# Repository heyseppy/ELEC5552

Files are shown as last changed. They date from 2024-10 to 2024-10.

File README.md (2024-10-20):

<p align="center">
  ELEC5552 Drone Image
  <h1>ELEC5552 Electrical Design Project</h1>
</p>

---

## Overview

This project encompasses hardware designs, build guides, and software implementations for developing a fully autonomous drone. The goal is to design and build a robust drone capable of autonomous line following, obstacle detection, and smooth transitions between manual and autonomous control modes.

### Key Features

- **Autonomous Line Following**  
  The drone adjusts its pitch and yaw to maintain alignment with a predefined path using a bottom-facing camera.

- **Obstacle Detection**  
  An ultrasonic sensor detects obstacles, allowing the drone to either stop or adjust its throttle to avoid collisions.

- **Safe Operation**  
  In the event of communication loss, the drone follows safety protocols to ensure secure operation.

- **Manual Mode**  
  The system enables manual control for the operator, with seamless switching between manual and autonomous modes.

---

## Hardware Requirements

- **Flight Controller**  
  Central unit that stabilizes and manages the drone’s flight based on input from sensors.

- **Bottom-facing Camera**  
  Provides vision for line/path detection to guide the drone during autonomous mode.

- **Ultrasonic Sensor**  
  Facilitates obstacle detection and altitude management to prevent collisions.

- **Motors and ESCs (Electronic Speed Controllers)**  
  Essential for precise control over throttle, pitch, and yaw during flight.

- **Radio or Wi-Fi Module**  
  Ensures wireless communication between the drone and the base station for real-time command transmission.

- **Battery (800mAh - 1S/2S)**  
  Powers the drone and onboard electronics.

---

## Software Requirements

- **Arduino IDE**  
  Development environment used to program the flight controller and integrate sensor inputs.

- **Communication Protocol**  
  Implements wireless communication between the drone and controller using protocols like LoRa, Wi-Fi, or proprietary radio systems.

- **Sensor Drivers**  
  Drivers or libraries are used for managing data from the ultrasonic sensor and camera.

---

## Contributors

- Jonathon Sader  
- William Hor  
- Sep Kimiaei  
- Carl Alvares  
- Liam Kubach  
- Aidan Crummey

---

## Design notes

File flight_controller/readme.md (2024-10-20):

## Understanding the CRSF Protocol

### What is CRSF?

**CRSF (Crossfire)** is a proprietary communication protocol developed by Team BlackSheep for long-range, low-latency communication between a transmitter and a receiver, typically used in RC (Radio Control) applications such as drones and other remote-controlled vehicles. CRSF is renowned for its high reliability, low latency, and efficient bandwidth utilization.

### Why CRSF?

- **Low Latency**: Ensures rapid response times, crucial for real-time control in dynamic environments.
- **High Reliability**: Maintains stable connections even in challenging conditions, minimizing packet loss.
- **Efficient Bandwidth**: Optimizes data transmission, allowing for more telemetry data without overloading the communication channel.
- **Extended Range**: Provides robust communication over longer distances compared to traditional RC protocols.

### CRSF in Team01 Firmware

In the Team01 Drone Control Firmware, CRSF is utilized to facilitate communication between the ESP32 microcontroller and the Flight Controller (FC). Here's how CRSF is integrated:

1. **UART Communication**: The ESP32 communicates with the FC via UART using designated TX and RX pins.
2. **CRSF Frames**: Data is encapsulated in CRSF frames, which include a synchronization byte, length, type, payload, and CRC for error checking.
3. **Telemetry Data**: The firmware parses incoming telemetry packets from the FC, extracting vital information such as battery status, RSSI, accelerometer readings, barometer data, and motor outputs.
4. **Control Commands**: The firmware sends control commands (e.g., Roll, Pitch, Yaw, Throttle, Arm/Disarm) to the FC by constructing and transmitting appropriate CRSF frames.
5. **Error Handling**: Implements CRC checks to ensure data integrity and handles reconnection logic in case of communication failures.

### CRSF Frame Structure

A typical CRSF frame consists of the following components:

1. **Sync Byte**: `0xC8` indicating the start of a CRSF frame.
2. **Length**: Specifies the total length of the frame.
3. **Type**: Indicates the type of data being transmitted (e.g., Binding, Channel Data, Telemetry).
4. **Payload**: Contains the actual data, such as channel values or telemetry information.
5. **CRC**: Cyclic Redundancy Check byte for error detection.

### CRC8 Calculation

The firmware includes a `crc8` function that calculates the CRC for a given data buffer. This ensures that the data transmitted and received is free from errors. The CRC8 uses a polynomial (`0xD5`) specific to the CRSF protocol.

```cpp
uint8_t crc8(const uint8_t *data, uint8_t len) {
  uint8_t crc = 0;
  while (len--) {
    crc ^= *data++;
    for (uint8_t i = 0; i < 8; i++) {
      if (crc & 0x80)
        crc = (crc << 1) ^ 0xD5; // Correct polynomial for CRSF
      else
        crc <<= 1;
    }
  }
  return crc;
}

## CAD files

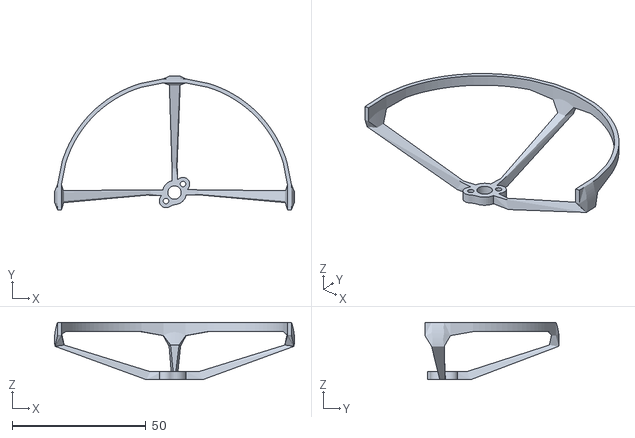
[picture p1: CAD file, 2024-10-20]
hardware/Drone Chassis/nanolr-guard-rear-right v4.stl
89.8 x 50.2 x 21.5

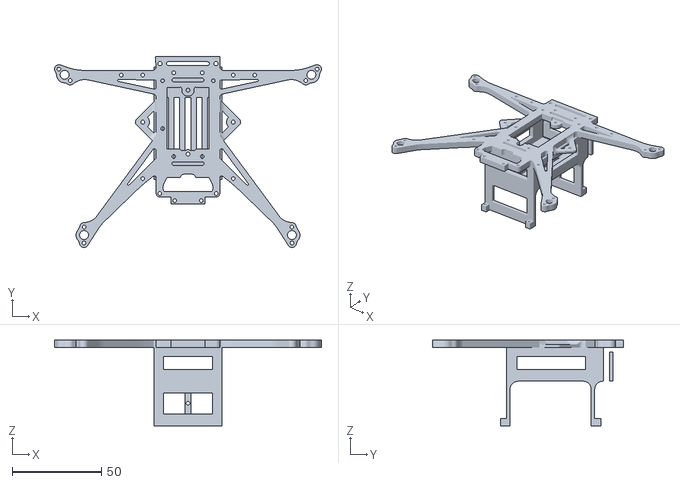
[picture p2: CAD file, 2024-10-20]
hardware/Drone Chassis/Top_Rev3 v11.stl
149.8 x 107.2 x 48.0

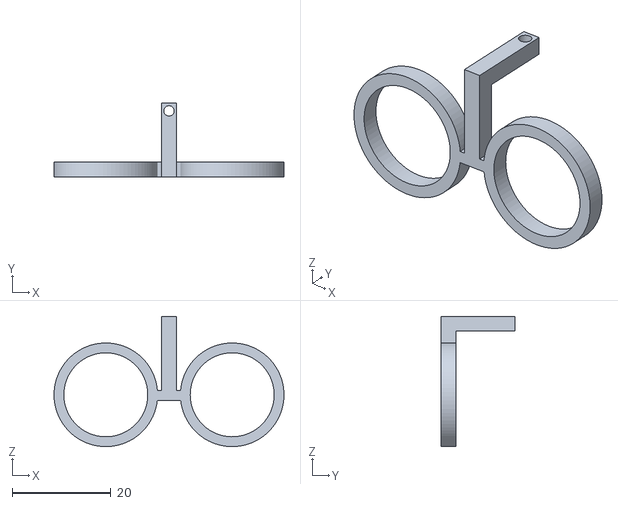
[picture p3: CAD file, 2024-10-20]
hardware/Drone Chassis/Ultra Sonic Holder 2 v4.stl
46.6 x 15.0 x 26.4

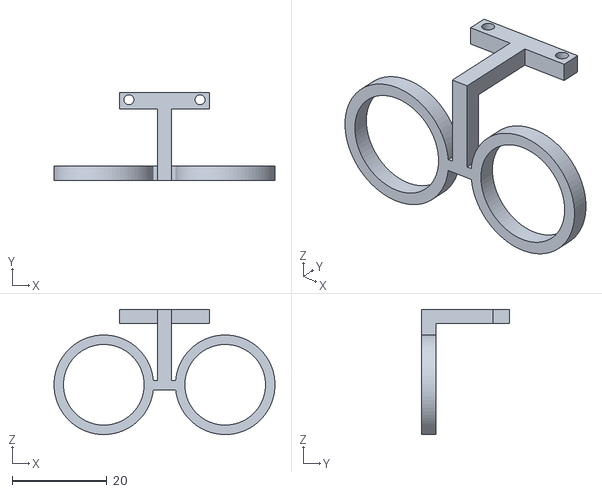
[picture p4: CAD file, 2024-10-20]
hardware/Drone Chassis/Ultra Sonic Holder v3.stl
46.6 x 18.5 x 26.4

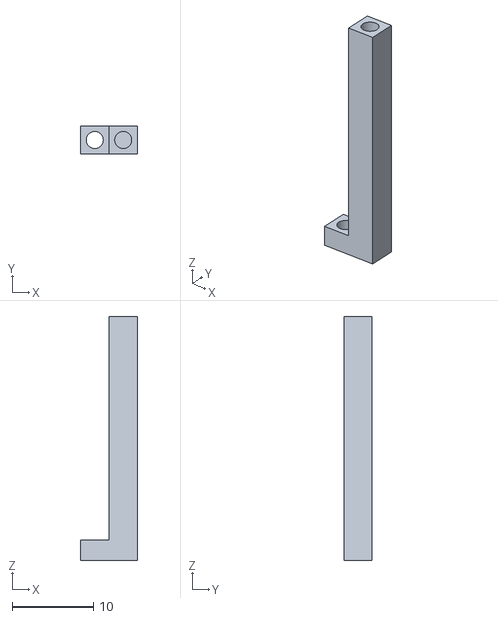
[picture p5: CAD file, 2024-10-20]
hardware/Drone Chassis/ESP Holder v8.stl
7.00 x 3.50 x 30.0

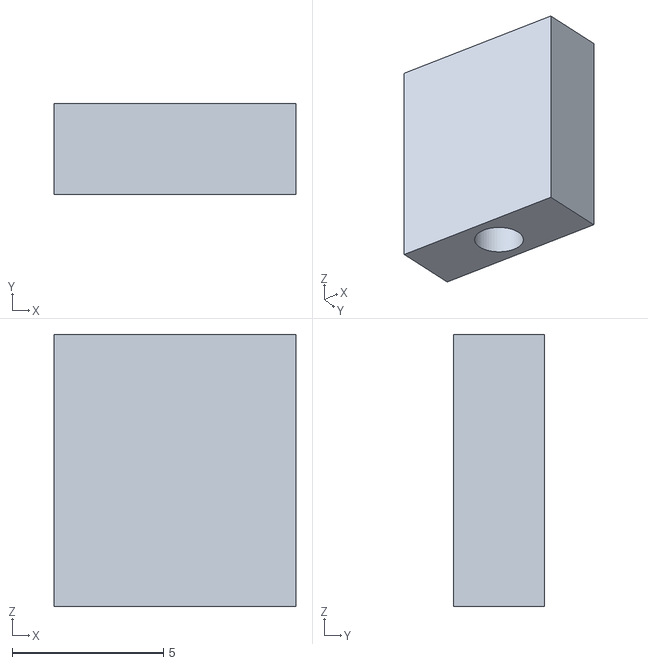
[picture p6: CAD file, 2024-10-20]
hardware/Drone Chassis/ESP Cam Holder v4.stl
8.00 x 3.00 x 9.00

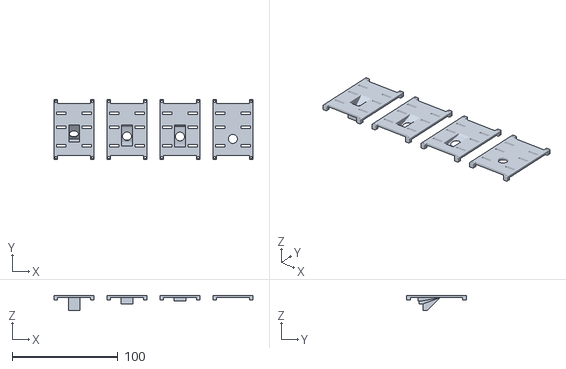
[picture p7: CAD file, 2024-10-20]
hardware/Drone Chassis/Cam Holders v12.stl
188.0 x 56.5 x 14.0

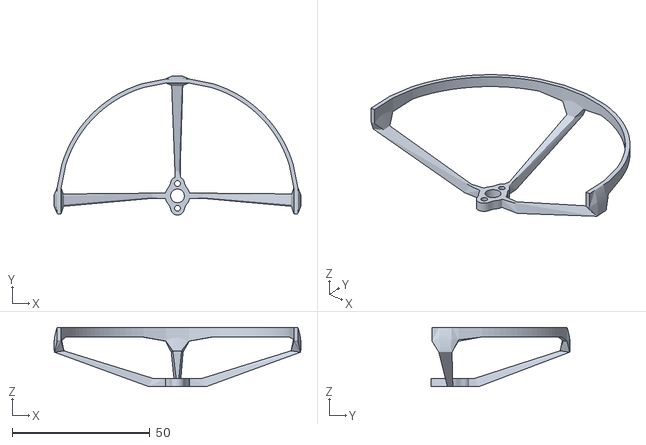
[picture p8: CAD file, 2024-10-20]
hardware/Drone Chassis/nanolr-guard-front v4.stl
89.8 x 50.6 x 21.5

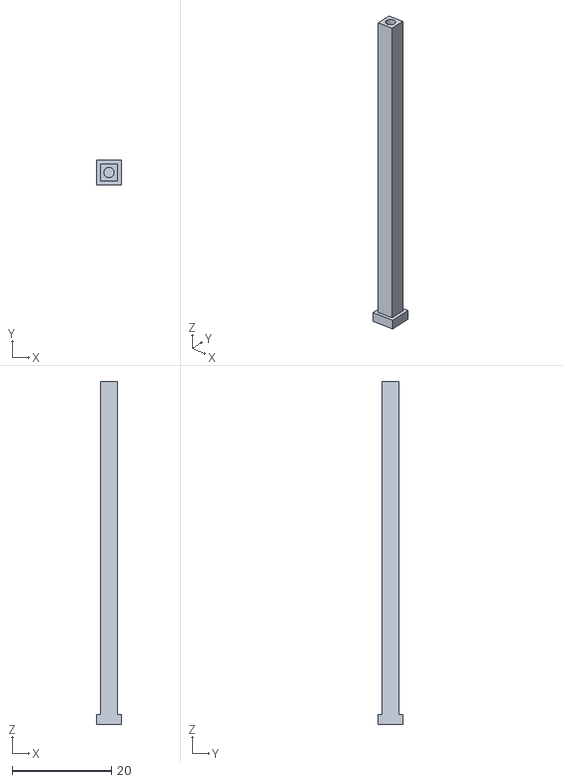
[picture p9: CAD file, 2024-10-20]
hardware/Drone Chassis/Leg v4.stl
5.00 x 5.00 x 69.0

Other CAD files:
hardware/Drone Chassis/nanolr-guard-rear-left v4.stl

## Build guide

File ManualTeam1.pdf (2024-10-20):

# Technical

# MANUAL

## Line-Following Drone

### Team01

## October 2024

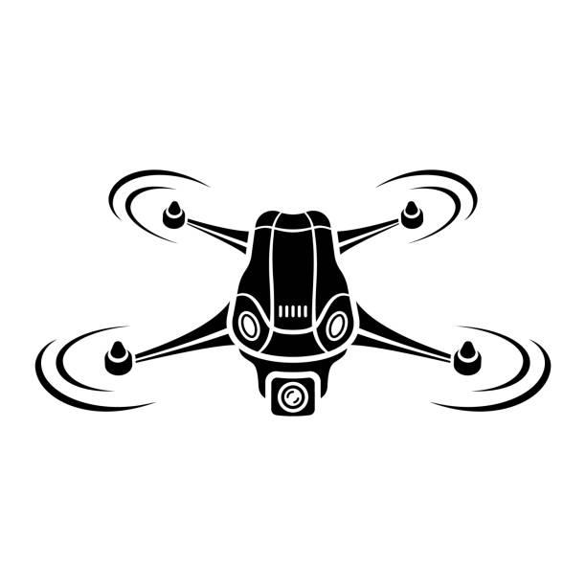
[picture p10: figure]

User’s Manual | Page ii

## USER'S MANUAL

### TABLE OF CONTENTS

Page #

A. GENERAL INFORMATION | A-1

### 1.1 System Precautions | A-1

### 1.2 System Prerequisites | A-2

### 1.2 Acknowledgement of Limitations | A-2

### 1.3 Preflight Checks | A-3

B. SYSTEM SUMMARY | B-1

### 2.1 Powering on Device | B-1

### 2.2 Connecting Controller | B-1

### 2.3 Toggling Modes | B-4

### 2.4 Tuning Device | B-1

### 1.0 General Information

User’s Manual

## 1.0 GENERAL INFORMATION

### 1.0 General Information

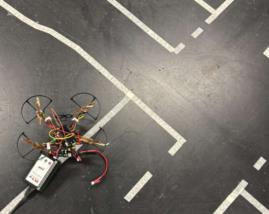
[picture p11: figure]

User’s Manual | Page A-1

## A. GENERAL INFORMATION

## 1.1 System Precautions

The safe operation of this drone relies on mitigating hazards to the surrounding environment, personnel and the product itself prior to operation. To achieve this, please adhere to the following recommendations:

1.1.1 Propellor Mounts

On top of each propellor, there are two Phillips-head screws that mount the blade to its relevant brushless motor. By applying torque with a standard Phillips screwdriver, ensure that each propellor is securely mounted.

Figure 1 Propellor Screw Positions

1.1.2 Intrusive Cabling

During manual handling, it is possible for the peripheral sensor or motor cables to protrude from their zip ties and make their way to the propellor region. Ensure that all these cables are moved away from the blades and secured in their zip ties.

Figure 2 Example of Intrusive Cabling

1.1.3 Safe Environment

As this drone is intended for indoor usage, alterations must be made such as enforcing the use of PPE (such as glasses) and keeping fire-extinguishers on hand as opposed to free flight in open areas. It is recommended the drone flies on a flat surface with a predefined line-marker.

Figure 3 Example of flat surface required for testing

### 1.0 General Information

User’s Manual | Page A-2

## 1.2 System Prerequisites

The following materials are required for successful manual and autonomous operation of the drone.

- 1x GPIO for connecting LiPo wall-charger.
- 1x Laptop with integrated Wi-Fi capabilities.

The following software is required:
- Operator GUI application provided in this suite.
- Python3 installed on the operator’s laptop with the following external packages.
- TKinter
- OpenCV
- Sockets

These tools are not required but significantly ease diagnostic processes:
- 1x 0x50mm Phillips-head Screwdriver
- 1x M2 Allen key
- 1x Spare 2S-800mAH battery.

## 1.2 Acknowledgement of Limitations

Despite this product being intended for indoor monitoring of MRG’s resources, it is important to acknowledge technical limitations that are involved.

An onboard monitoring system ensures that the drone hovers on the spot in the presence of an obstacle. Whilst this is true, the system is significantly limited in the range and distance it can observe obstacles from. Although a hard limit of 20cm is set for the obstacle, electronic noise in the sensor readings may require user tuning of inputs to account for actual distance.

In a similar manner, the height stabilisation sensors are comprised of ultrasonic sensors. As a result, the same uncertainty or noise will be present. Manual tuning will be required by the operator in order to effectively operate.

### 1.0 General Information

User’s Manual | Page A-3

## 1.3 Preflight Checks

1. Power On and Connectivity:
- Ensure the drone's battery is fully charged.
- Power on the drone and confirm that all onboard systems (ESP32, ESP32-CAM, flight controller) are functioning. This can be done by checking whether a RED LED is on for each component.
- Connect the controller system to the drone via Wi-Fi (SSID: "ESP32-Test-AP", Password: "12345678").
- Confirm that the IP addresses are correctly configured (ESP32 IP: 172.20.10.13, ESP32-CAM IP: 172.20.10.12).
- Verify the TCP connection to the ESP32 (port 12345) and ensure the control interface shows "Connected."
2. Sensor and Obstacle Detection:
- Verify obstacle detection data is being received from the ESP32 (obstacle distance shown in the GUI).
- Ensure the distance label is updated with real-time data, indicating proper sensor functionality.
3. Video Feed Check:
- Confirm that the live camera feed from the ESP32-CAM is visible in the GUI.
- Check that the camera feed updates smoothly, and that line angle detection is operational (angle displayed correctly).
- Verify that the image resolution and frame rate are acceptable.
4. Control Interface Check:
- Test all control modes (Emergency Stop, Hover Mode, Manual Mode, Autonomous Control).
- Send a command to the drone (e.g., HOVER, MANUAL, AUTO) and verify that the drone responds appropriately.
- Ensure the drone state is correctly displayed in the GUI (e.g., "Hovering," "Following Line").
5. Throttle and Flight Controller:
- Ensure that the throttle, pitch, and yaw commands can be sent and acknowledged.
6. Simulation Mode (Optional):
- Test the simulation by toggling it on and off to confirm drone states (e.g., "Lifting," "Hovering") update in the GUI.
7. Failsafe and Emergency Stop:
- Test the Emergency Stop function and confirm the motors stop immediately.
- Verify that a disconnection is properly handled, and the system attempts to reconnect automatically.

Once all these checks are confirmed, the drone is ready for flight.

### 2.0 System Summary

User’s Manual

## 2.0 SYSTEM OPERATION

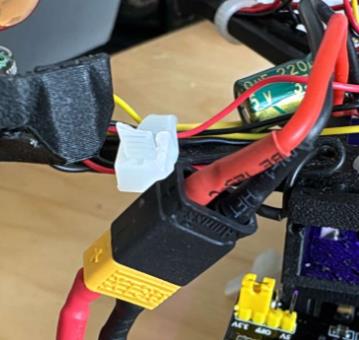
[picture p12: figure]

User’s Manual | Page B-1

## B. SYSTEM SUMMARY

## 2.1 Powering on Device

1. After ensuring PPE is appropriately adorned, place the drone on a thin black line to start.
2. Whilst keeping the drone flat on the ground, plug in the LiPo XT30 connector from the battery to the flight controller. Ensure that there is no debris lodged between the connectors.
3. Listen for a dual-tone beep. Once this beep is observed it means that the system is armed and the Team01 drone is energized.

Figure 4 Initial Power Connection

4. The device is now ready for remote connection.

## 2.2 Connecting Controller

1. Open the Wi-Fi connection settings on the operator’s device. Note that Linux, Windows and MACOS are supported.
2. Once in the network choices panel, select the Team01 Drone option and enter the password 12345678.
3. After connecting and ensuring a stable network connection, launch the operator_gui.py by running the following command in a terminal window:
Python3 operator_gui.py
4. Soon, a screen will launch with the following interface.

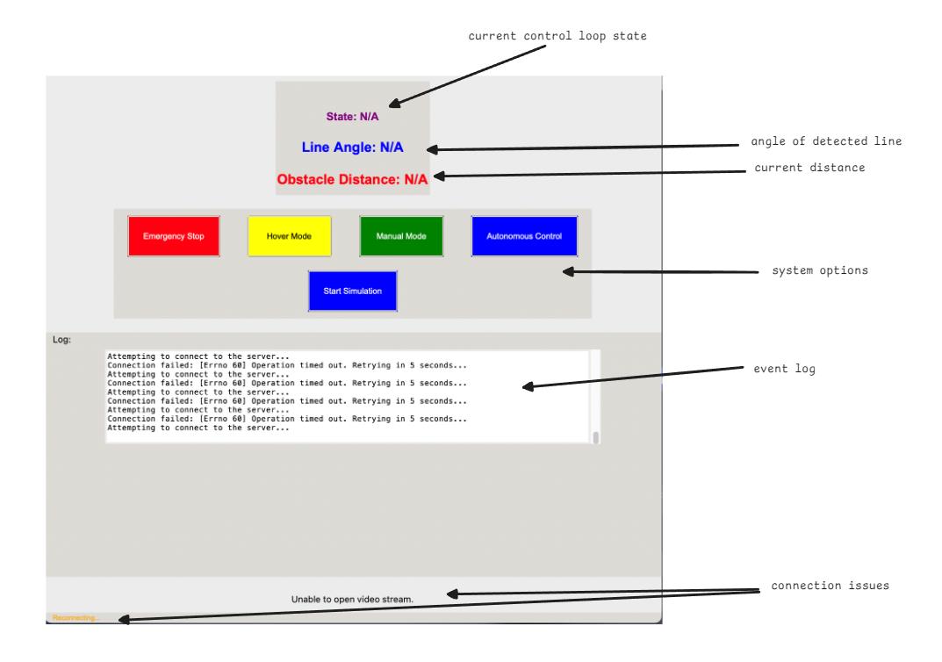
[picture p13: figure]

User’s Manual | Page B-2

Figure 5 Operator GUI in connecting state

5. Observing the event log in the GUI, we can see that the telemetry data is slowly loading in.
6. Once fully connected, the operator should be able to see the following screen.

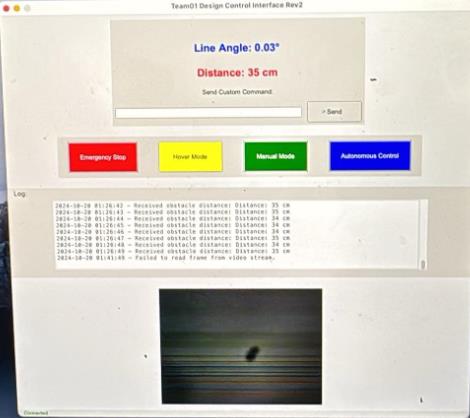
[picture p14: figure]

User’s Manual | Page B-3

Figure 6 Primed operator terminal

7. Ensure that the camera feed is clean by observing any debris on the feed. In the case for the image above, it is evident that a crack in the feed will produce undesired results and will require replacement.
8. Check that the line angle and obstacle distance sensor are calibrated correctly. If they are not please refer to the tuning section within this report.
9. Once steps (7) and (8) are validated proceed to the next section.

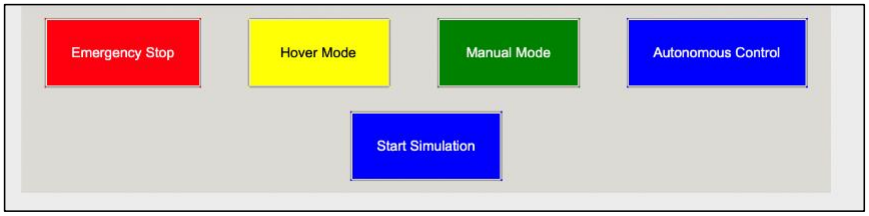
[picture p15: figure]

User’s Manual | Page B-4

## 2.3 Toggling Modes

The Team01 Drone features a multitude of potential actions. Please observe the descriptions provided below and select accordingly.

Figure 7 Example modes

Table 1: Buttons and Actions

Command | Action
Emergency Stop | Immediately cuts throttle to the ESCS. Note that it does not deenergise the system and will result in a rapid descent from any altitude.
Hover Mode | Will maintain flight at the given altitude, pausing continuous operation until advised otherwise.
Manual Mode | Will begin manual mode which will be later added into the system enabling settings such as manual flying forward and backwards.
Autonomous Control | Will begin the autonomous flight control system: 1. Hover to predefined height. 2. Check for obstacles (hover until obstacle removed) 3. Move to intended flight angle. 4. Continue until line angle is no longer present.
Start Simulation | Simulate the procedure outlined above.

### 10.0 Appendix

User’s Manual | Page B-1

## 2.4 Tuning Device

To account for dynamic environments whilst promoting user configurability, the following parameters can be defined by the operator.

Table 2: Tunable configurations

Parameter | Definition
Obstacle Distance | Value in centimetres.
Height Stabilisation | Value in centimetres.
Heartbeat Freq | Value for checks per minute.

These settings can be configured in lines 10-13 in the operator_gui.py file.

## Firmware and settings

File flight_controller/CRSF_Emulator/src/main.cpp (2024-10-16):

#include <Arduino.h>
#include <WiFi.h>
#include <ESPAsyncWebServer.h>
#include <AsyncTCP.h>
#include <LittleFS.h>
#include <ArduinoJson.h>

// Define UART Pins
#define TXD_PIN (GPIO_NUM_17) // ESP32 TX Pin connected to FC RX
#define RXD_PIN (GPIO_NUM_16) // ESP32 RX Pin connected to FC TX

// Define CRSF Constants
#define CRSF_SYNC_BYTE 0xC8

// Define Wi-Fi Credentials
const char* ssid = "Team01Drone";
const char* password = "a1b2c3d4e5";

// Initialize Web Server and WebSocket
AsyncWebServer server(80);
AsyncWebSocket ws("/ws");

// Define Channel Values (Assuming 16 channels)
uint16_t channels[16];

// Define Payload and CRSF Frame Buffers
uint8_t payload[22];
uint8_t crsfFrame[26];

// Control Variables for Channels
float roll = 0.0;     // Channel 1
float pitch = 0.0;    // Channel 2
float throttle = 0.0; // Channel 3
float yaw = 0.0;      // Channel 4
bool isArmed = false; // Channel 5 (Aux 1)

// Telemetry Variables
float batteryVoltage = 0.0;
float batteryCurrent = 0.0;
uint8_t rssi = 0;

// Accelerometer Data Variables
float accRoll = 0.0;
float accPitch = 0.0;
float accYaw = 0.0;

// Barometer Data
float baroAltitude = 0.0;
float verticalSpeed = 0.0;

// Flight Mode
String flightMode = "Unknown";

// Vibration Levels
float vibrationX = 0.0;
float vibrationY = 0.0;
float vibrationZ = 0.0;

// Motor Outputs
uint16_t motorOutputs[8] = {0}; // Initialize motor outputs (Adjust size as needed)

// Temperature Sensors
float fcTemperature = 0.0;

// Warning Messages
String warningMessage = "None";

// Function Prototypes
void initializeChannels();
void updateChannels();
void packChannels();
uint8_t crc8(const uint8_t *data, uint8_t len);
void buildCrsfFrame();
void parseTelemetryPacket(uint8_t *buffer, uint8_t length);
void readTelemetry();
void sendTelemetry();
void onWebSocketEvent(AsyncWebSocket * server, AsyncWebSocketClient * client, AwsEventType type,
                      void * arg, uint8_t * data, size_t len);

// Initialize Channels with Neutral Values
void initializeChannels() {
  for (int i = 0; i < 16; i++) {
    channels[i] = 992; // Neutral value for all channels
  }
}

// Update Channel Values Based on Control Inputs
void updateChannels() {
  channels[0] = constrain((int)(992 + (roll * 820)), 172, 1811);      // Roll (Channel 1)
  channels[1] = constrain((int)(992 + (pitch * 820)), 172, 1811);     // Pitch (Channel 2)
  channels[2] = constrain((int)(50 + (throttle * 1811)), 0, 1811); // Throttle (Channel 3)
  channels[3] = constrain((int)(992 + (yaw * 820)), 172, 1811);       // Yaw (Channel 4)

  // Channel 5 for Arm/Disarm (Aux 1)
  channels[4] = isArmed ? 1811 : 172; // High value for armed, low for disarmed
}

// Pack Channel Values into CRSF Payload
void packChannels() {
  uint8_t payloadIndex = 0;
  uint32_t bitBuffer = 0;
  uint8_t bitsInBuffer = 0;

  memset(payload, 0, sizeof(payload));

  for (uint8_t i = 0; i < 16; i++) {
    bitBuffer |= ((uint32_t)(channels[i] & 0x07FF)) << bitsInBuffer;
    bitsInBuffer += 11;

    while (bitsInBuffer >= 8) {
      payload[payloadIndex++] = bitBuffer & 0xFF;
      bitBuffer >>= 8;
      bitsInBuffer -= 8;
    }
  }

  if (payloadIndex < 22) {
    payload[payloadIndex] = bitBuffer & 0xFF;
  }
}

// Calculate CRC8 for CRSF Frame
uint8_t crc8(const uint8_t *data, uint8_t len) {
  uint8_t crc = 0;
  while (len--) {
    crc ^= *data++;
    for (uint8_t i = 0; i < 8; i++) {
      if (crc & 0x80)
        crc = (crc << 1) ^ 0xD5; // Correct polynomial for CRSF
      else
        crc <<= 1;
    }
  }
  return crc;
}

// Build CRSF Frame with Payload and CRC
void buildCrsfFrame() {
  crsfFrame[0] = CRSF_SYNC_BYTE; // Start of Frame
  crsfFrame[1] = 24;            // Length
  crsfFrame[2] = 0x16;          // Type (e.g., Binding, Channel Data)

  memcpy(&crsfFrame[3], payload, 22); // Copy Payload

  crsfFrame[25] = crc8(&crsfFrame[2], 23); // Compute CRC8
}

// Parse Telemetry Packet from FC
void parseTelemetryPacket(uint8_t *buffer, uint8_t length) {
  uint8_t type = buffer[0];
  uint8_t *payload = &buffer[1];
  uint8_t payloadLength = length - 1;

  switch (type) {
    case 0x07: // Link statistics
      if (payloadLength >= 10) {
        rssi = payload[0]; // RSSI in dBm
        // Additional link statistics can be parsed here if needed
      }
      break;
    case 0x08: // Battery voltage and current
      if (payloadLength >= 4) {
        batteryVoltage = (payload[0] << 8 | payload[1]) / 100.0; // Voltage in Volts
        batteryCurrent = (payload[2] << 8 | payload[3]) / 100.0; // Current in Amps
      }
      break;
    case 0x1E: // Attitude (Roll, Pitch, Yaw)
      if (payloadLength >= 6) {
        int16_t rawRoll = (int16_t)(payload[0] << 8 | payload[1]);
        int16_t rawPitch = (int16_t)(payload[2] << 8 | payload[3]);
        int16_t rawYaw = (int16_t)(payload[4] << 8 | payload[5]);

        // Convert to degrees (assuming values are in centidegrees)
        accRoll = rawRoll / 100.0;
        accPitch = rawPitch / 100.0;
        accYaw = rawYaw / 100.0;
      }
      break;
    case 0x10: // Barometer data
      if (payloadLength >= 6) {
        int32_t rawAltitude = (int32_t)(payload[0] << 24 | payload[1] << 16 | payload[2] << 8 | payload[3]);
        int16_t rawVSpeed = (int16_t)(payload[4] << 8 | payload[5]);

        baroAltitude = rawAltitude / 100.0;     // Convert cm to meters
        verticalSpeed = rawVSpeed / 100.0;      // Convert cm/s to m/s
      }
      break;
    case 0x21: // Flight mode
      // Flight mode is sent as a variable length string
      flightMode = "";
      for (uint8_t i = 0; i < payloadLength; i++) {
        flightMode += (char)payload[i];
      }
      break;
    case 0x26: // Motor outputs
      {
        uint8_t numMotors = payloadLength / 2; // Each motor output is 2 bytes
        for (uint8_t i = 0; i < numMotors && i < 8; i++) {
          motorOutputs[i] = (uint16_t)(payload[2*i] << 8 | payload[2*i + 1]);
        }
      }
      break;
    case 0x0E: // Temperature sensors
      if (payloadLength >= 2) {
        int16_t rawTemp = (int16_t)(payload[0] << 8 | payload[1]);
        fcTemperature = rawTemp / 100.0; // Temperature in degrees Celsius
      }
      break;
    case 0x22: // Warning messages
      // Warning message is sent as a variable length string
      warningMessage = "";
      for (uint8_t i = 0; i < payloadLength; i++) {
        warningMessage += (char)payload[i];
      }
      break;
    case 0x30: // Vibration levels (Assuming custom message type 0x30)
      if (payloadLength >= 6) {
        int16_t rawVibX = (int16_t)(payload[0] << 8 | payload[1]);
        int16_t rawVibY = (int16_t)(payload[2] << 8 | payload[3]);
        int16_t rawVibZ = (int16_t)(payload[4] << 8 | payload[5]);

        // Convert to g's or appropriate units based on FC output
        vibrationX = rawVibX / 1000.0;
        vibrationY = rawVibY / 1000.0;
        vibrationZ = rawVibZ / 1000.0;
      }
      break;
    default:
      // Unknown telemetry type
      break;
  }
}

// Read Telemetry Data from FC via UART2
void readTelemetry() {
  static uint8_t buffer[64];
  static uint8_t bufferIndex = 0;

  while (Serial2.available()) {
    uint8_t byte = Serial2.read();

    // Check for start of packet (Sync Byte)
    if (byte == CRSF_SYNC_BYTE) {
      bufferIndex = 0;
      buffer[bufferIndex++] = byte;
    } else if (bufferIndex > 0) {
      buffer[bufferIndex++] = byte;

      // Check if we have at least the length byte
      if (bufferIndex == 2) {
        // buffer[1] is the length
        if (buffer[1] > sizeof(buffer) - 2) {
          // Invalid length, reset buffer
          bufferIndex = 0;
        }
      } else if (bufferIndex == buffer[1] + 2) {
        // We have the full packet
        uint8_t length = buffer[1];
        uint8_t calculatedCrc = crc8(&buffer[2], length - 1);
        uint8_t receivedCrc = buffer[bufferIndex - 1];

        if (calculatedCrc == receivedCrc) {
          // Valid packet, parse telemetry
          parseTelemetryPacket(&buffer[2], length - 1);
        }
        // Reset buffer for next packet
        bufferIndex = 0;
      }
    }
  }
}

// Send Telemetry Data via WebSocket
void sendTelemetry() {
  // Use StaticJsonDocument for stack allocation with a fixed size
  StaticJsonDocument<1024> jsonDoc; // Adjust the size as needed

  // Populate the JSON document with telemetry data
  jsonDoc["voltage"] = batteryVoltage;
  jsonDoc["current"] = batteryCurrent;
  jsonDoc["rssi"] = rssi;

  // Accelerometer data
  jsonDoc["accRoll"] = accRoll;
  jsonDoc["accPitch"] = accPitch;
  jsonDoc["accYaw"] = accYaw;

  // Barometer data
  jsonDoc["baroAltitude"] = baroAltitude;
  jsonDoc["verticalSpeed"] = verticalSpeed;

  // Flight mode
  jsonDoc["flightMode"] = flightMode;

  // Vibration levels
  jsonDoc["vibrationX"] = vibrationX;
  jsonDoc["vibrationY"] = vibrationY;
  jsonDoc["vibrationZ"] = vibrationZ;

  // Motor outputs
  JsonArray motorArray = jsonDoc["motorOutputs"].to<JsonArray>();
  for (uint8_t i = 0; i < 8; i++) { // Adjust based on the number of motors
    motorArray.add(motorOutputs[i]);
  }

  // Temperature sensors
  jsonDoc["fcTemperature"] = fcTemperature;

  // Warning messages
  jsonDoc["warningMessage"] = warningMessage;

  // Serialize the JSON document to a string
  String jsonString;
  serializeJson(jsonDoc, jsonString);

  // Send the JSON string over WebSocket to all connected clients
  ws.textAll(jsonString);
}

// Handle WebSocket Events
void onWebSocketEvent(AsyncWebSocket * server, AsyncWebSocketClient * client, AwsEventType type,
                      void * arg, uint8_t * data, size_t len) {
  if (type == WS_EVT_CONNECT) {
    Serial.println("WebSocket client connected");
  } else if (type == WS_EVT_DISCONNECT) {
    Serial.println("WebSocket client disconnected");
  }
}

// Setup Function
void setup() {
  // Initialize Serial for debugging
  Serial.begin(115200);
  
  // Initialize UART2 for CRSF communication
  Serial2.begin(420000, SERIAL_8N1, RXD_PIN, TXD_PIN); // High baud rate for CRSF

  // Initialize Channel Values
  initializeChannels();

  // Initialize Wi-Fi as Access Point
  WiFi.softAP(ssid, password);
  IPAddress IP = WiFi.softAPIP();
  Serial.print("AP IP address: ");
  Serial.println(IP);

  // Initialize LittleFS for File System
  if (!LittleFS.begin()) {
    Serial.println("An error has occurred while mounting LittleFS");
    return;
  }

  // Serve the Web Page from LittleFS
  server.on("/", HTTP_GET, [](AsyncWebServerRequest *request){
    request->send(LittleFS, "/index.html", "text/html");
  });

  // Handle Control Updates via HTTP GET Requests
  server.on("/update", HTTP_GET, [](AsyncWebServerRequest *request){
    String inputMessage;

    // Handle Roll Update
    if (request->hasParam("roll")) {
      inputMessage = request->getParam("roll")->value();
      roll = inputMessage.toFloat() / 100.0;
      Serial.println("Roll set to " + String(roll * 100) + "%");
    }

    // Handle Pitch Update
    if (request->hasParam("pitch")) {
      inputMessage = request->getParam("pitch")->value();
      pitch = inputMessage.toFloat() / 100.0;
      Serial.println("Pitch set to " + String(pitch * 100) + "%");
    }

    // Handle Yaw Update
    if (request->hasParam("yaw")) {
      inputMessage = request->getParam("yaw")->value();
      yaw = inputMessage.toFloat() / 100.0;
      Serial.println("Yaw set to " + String(yaw * 100) + "%");
    }

    // Handle Throttle Update
    if (request->hasParam("throttle")) {
      inputMessage = request->getParam("throttle")->value();
      throttle = inputMessage.toFloat() / 100.0;
      Serial.println("Throttle set to " + String(throttle * 100) + "%");
    }

    // Handle Arm/Disarm Update
    if (request->hasParam("arm")) {
      inputMessage = request->getParam("arm")->value();
      isArmed = (inputMessage == "1");
      Serial.println(isArmed ? "Armed" : "Disarmed");
    }

    // Handle Stop Motors Command
    if (request->hasParam("stop")) {
      // Stop motors by setting throttle to zero and disarming
      throttle = 0.0;
      isArmed = false;

      // Reset Roll, Pitch, and Yaw to zero
      roll = 0.0;
      pitch = 0.0;
      yaw = 0.0;

      Serial.println("Motors stopped and controls reset");
    }

    // Respond with No Content
    request->send(204);
  });

  // Attach WebSocket Event Handler
  ws.onEvent(onWebSocketEvent);
  server.addHandler(&ws);

  // Start the Web Server
  server.begin();
}

// Global Variable to Track Telemetry Sending Interval
unsigned long lastTelemetryTime = 0;

// Main Loop Function
void loop() {
  // // Read Telemetry Data from FC
  // readTelemetry();

  // // Check if it's time to send telemetry data
  // unsigned long currentTime = millis();
  // if (currentTime - lastTelemetryTime >= 500) { // Send every 500 ms
  //   sendTelemetry();
  //   lastTelemetryTime = currentTime;
  // }

  // Update Channel Values Based on Controls
  updateChannels();

  // Pack Channel Values into CRSF Payload
  packChannels();

  // Build CRSF Frame with Payload and CRC
  buildCrsfFrame();

  // Send CRSF Frame to FC via UART2
  Serial2.write(crsfFrame, 26); // CRSF frame size is 26 bytes

  // Clean Up Disconnected WebSocket Clients
  ws.cleanupClients();

  // Delay to Maintain Update Rate (50Hz)
  delay(30); // 20 ms delay
}

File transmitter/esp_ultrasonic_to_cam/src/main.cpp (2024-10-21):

#include "esp_camera.h"
#include <WiFi.h>
#include <AsyncTCP.h>
#include <ESPAsyncWebServer.h>

// Camera model selection
#define CAMERA_MODEL_AI_THINKER

// WiFi credentials
const char* ssid = "iPhone";
const char* password = "12345678";

// TCP socket server credentials
const char* socket_host = "192.168.1.10";  // Replace with the socket server's IP address
const int socket_port = 1234;              // Replace with the socket server's port

// Create AsyncWebServer object on port 80
AsyncWebServer server(80);

WiFiClient socketClient;

// Camera configuration for AI-Thinker
#define PWDN_GPIO_NUM     32
#define RESET_GPIO_NUM    -1
#define XCLK_GPIO_NUM      0
#define SIOD_GPIO_NUM     26
#define SIOC_GPIO_NUM     27
#define Y9_GPIO_NUM       35
#define Y8_GPIO_NUM       34
#define Y7_GPIO_NUM       39
#define Y6_GPIO_NUM       36
#define Y5_GPIO_NUM       21
#define Y4_GPIO_NUM       19
#define Y3_GPIO_NUM       18
#define Y2_GPIO_NUM        5
#define VSYNC_GPIO_NUM    25
#define HREF_GPIO_NUM     23
#define PCLK_GPIO_NUM     22

// Function to start the camera server
void startCameraServer();

// Function to handle socket communication
void handleSocketConnection(void* parameter);

void setup() {
  // Initialize serial communication for USB debugging
  Serial.begin(115200);
  Serial.setDebugOutput(true);
  Serial.println();

  // Camera configuration
  camera_config_t config;
  config.ledc_channel = LEDC_CHANNEL_0;
  config.ledc_timer = LEDC_TIMER_0;
  config.pin_d0 = Y2_GPIO_NUM;
  config.pin_d1 = Y3_GPIO_NUM;
  config.pin_d2 = Y4_GPIO_NUM;
  config.pin_d3 = Y5_GPIO_NUM;
  config.pin_d4 = Y6_GPIO_NUM;
  config.pin_d5 = Y7_GPIO_NUM;
  config.pin_d6 = Y8_GPIO_NUM;
  config.pin_d7 = Y9_GPIO_NUM;
  config.pin_xclk = XCLK_GPIO_NUM;
  config.pin_pclk = PCLK_GPIO_NUM;
  config.pin_vsync = VSYNC_GPIO_NUM;
  config.pin_href = HREF_GPIO_NUM;
  config.pin_sscb_sda = SIOD_GPIO_NUM;
  config.pin_sscb_scl = SIOC_GPIO_NUM;
  config.pin_pwdn = PWDN_GPIO_NUM;
  config.pin_reset = RESET_GPIO_NUM;
  config.xclk_freq_hz = 20000000;
  config.pixel_format = PIXFORMAT_JPEG;

  // Set camera settings based on PSRAM availability
  if (psramFound()) {
    config.frame_size = FRAMESIZE_UXGA;
    config.jpeg_quality = 10;
    config.fb_count = 2;
  } else {
    config.frame_size = FRAMESIZE_SVGA;
    config.jpeg_quality = 12;
    config.fb_count = 1;
  }

  // Initialize the camera
  esp_err_t err = esp_camera_init(&config);
  if (err != ESP_OK) {
    Serial.printf("Camera init failed with error 0x%x", err);
    return;
  }

  // Set a lower frame size for faster streaming
  sensor_t* s = esp_camera_sensor_get();
  s->set_framesize(s, FRAMESIZE_QVGA);  // Lower resolution for faster streaming

  // Initialize WiFi
  WiFi.begin(ssid, password);
  while (WiFi.status() != WL_CONNECTED) {
    delay(500);
    Serial.print(".");
  }
  Serial.println("");
  Serial.println("WiFi connected");

  // Start the camera server
  startCameraServer();

  // Start the socket client in a separate task to handle TCP connection and data
  xTaskCreate(handleSocketConnection, "Socket Task", 4096, NULL, 1, NULL);

  Serial.print("Camera and Socket Client ready! Use 'http://");
  Serial.print(WiFi.localIP());
  Serial.println("' to connect");
}

void loop() {
  // Main loop remains empty, as socket handling runs in a separate task
  delay(10000);  // Delay to keep loop idle
}

// Function to handle the socket connection and receive ultrasonic data
void handleSocketConnection(void* parameter) {
  while (true) {
    // Attempt to connect to the transmitter (TCP server)
    if (!socketClient.connected()) {
      Serial.println("Connecting to the socket server...");
      if (socketClient.connect(socket_host, socket_port)) {
        Serial.println("Connected to the socket server.");
      } else {
        Serial.println("Failed to connect to the socket server.");
        delay(5000);  // Wait before retrying
        continue;
      }
    }

    // Read data from the socket when connected
    while (socketClient.connected()) {
      if (socketClient.available()) {
        String data = socketClient.readStringUntil('\n');  // Read the data sent by the transmitter
        Serial.println("Received ultrasonic distance: " + data);  // Print received data to serial
      }
      delay(100);  // Add some delay to avoid overwhelming the loop
    }

    // If disconnected, attempt to reconnect
    if (!socketClient.connected()) {
      Serial.println("Socket disconnected. Reconnecting...");
    }
    delay(1000);  // Wait before attempting to reconnect
  }
}

// Dummy camera server function
void startCameraServer() {
  // This is a placeholder for the actual code to start a camera web server
  Serial.println("Camera server started.");
}

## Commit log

2024-10-16 changed throttle gain and ssid
2024-10-19 updated camera code
2024-10-19 ESP32 ultrasonic read and send over wifi to camera working
2024-10-20 Drone Chassis Upload
2024-10-20 All Drone Chassis STL File Components Uploaded + Fusion Final Drone Design
    [Cam Holders v12.stl, ESP Cam Holder v4.stl, ESP Holder v8.stl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]
2024-10-20 added mechanical fillets
    [Cam Holders v12.stl, ESP Cam Holder v4.stl, ESP Holder v8.stl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]
2024-10-21 added ultrasonic over phone hotspot
